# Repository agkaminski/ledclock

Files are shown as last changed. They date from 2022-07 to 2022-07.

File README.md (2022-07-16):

# LEDclock
Big DIY clock based on LED filaments.
# Introduction
LEDclock project is a simple, yet very big and bright clock based on chinesium 3V LED filaments (designed to look like a incadescent bulb tungsten filament... from the distance, I guess).<br><br>
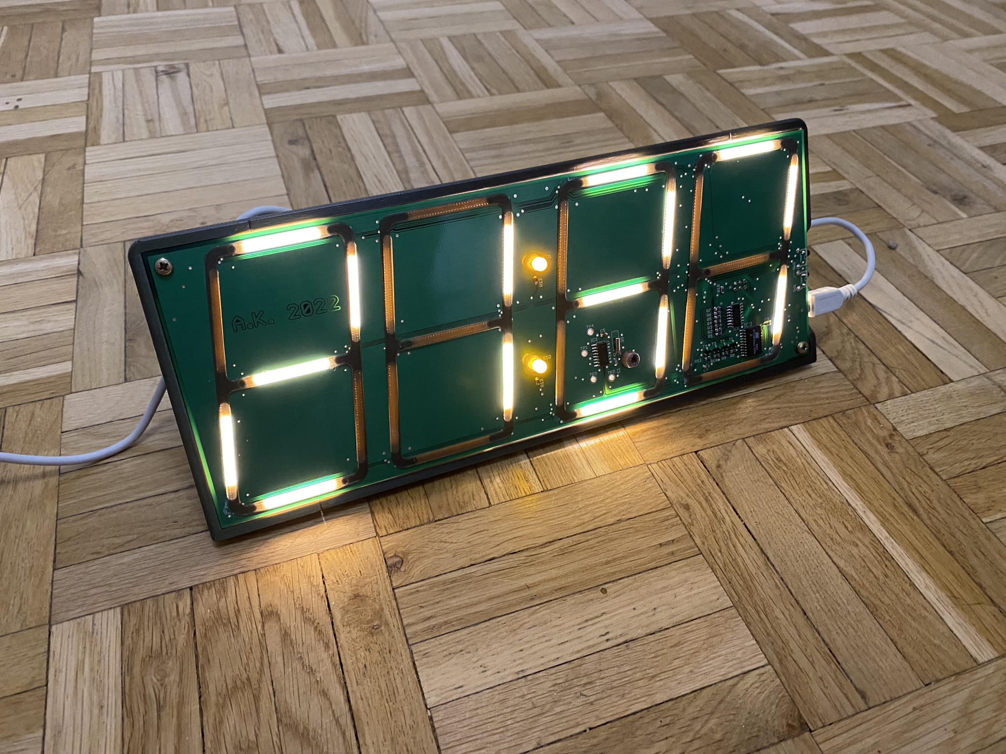
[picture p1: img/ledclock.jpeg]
LEDclock

# Features
- 24 hour clock,
- time setting via two buttons (one for minutes, one for hours),
- long press button to set time faster,
- blinking after power loss to indicate that the time is incorrect,
- RTC calibration with 1 ppm precision (+- 999 ppms),
- slow, gradual enabling/disabling changed screen segments (PWM),
- brightness setting,
- watchdog,
- calibration and brighness storage on the EEPROM.
# How to
To increment minutes press upper button, to increment hours press lower button. Long press for fast change
Press both buttons long to change mode. Available modes:
- RTC calibration,
- brightness setting,
- normal operation (clock mode).
After 5 seconds of buttons not being pressed display will return to clock mode.
## RTC calibration
Display: Cxxx for positive (making clock faster), Exxx for negative calibration. Press upper button to increase calibration value, lower button to decrease. Allows calibration from -999 to 999 ppm.
## Brighness
Display: b  x. Press upper button to increase brightness, lower to decrease. Brightness levels from 0 to 8 are available.
# I want to build one!
That's great! I am providing everything you need to make one yourself.
## Making PCB
Send gerber files to the PCB manufactuer of your choice. Make sure to get 28 milled slots done - it is essential, as LEDs are mounted on the bottom side and are viewed from the top side.
## Collecting elements
Please see the bom.csv file with all needed components. You can get LED filaments from here https://pl.aliexpress.com/item/4000478265055.html. Make sure to get 3V version!
## Soldering
This project uses pretty much only SMD elements, but all of them can be mounted using basic soldering iron.
**Dot LEDs can interfere with the ISP interface (depending on the programmer)!** Mount R12 and R13 resistors *after* downloading FW to the board.<br>
Watch out for LED filaments polarisation. + side is marked by a small hole in the lead - solder this side to the "common" side (the side that is connected to the neighbour LEDs).
## Sofware needed
To build FW you need *avr-gcc* along with *avr-libc*. To download the FW to the MCU you need *avrdude*.
## Downloading FW
My suggestion is to use USBasp programmer and avrdude software tool. I've provided needed commands in Makefile.
First we need to set fuse byte to change default 1 MHz CPU clock to 8 MHz:<br>
*make fuse*<br>
then we can download FW:<br>
*make install*<br>
Done! The clock should now be ready to be used.
## Housing 3D print
Housing is too big for most 3D printers to fit, so it was designed to be able to split into 3 parts. You need to split 30 mm on both sides. Three pieces can then be reattached by using 4 M4x25 (conical head) and 2 M3x50 screws. Many other screw lengths will do the trick. PCB is attached to the housing using 2 M3x8 screws.<br><br>
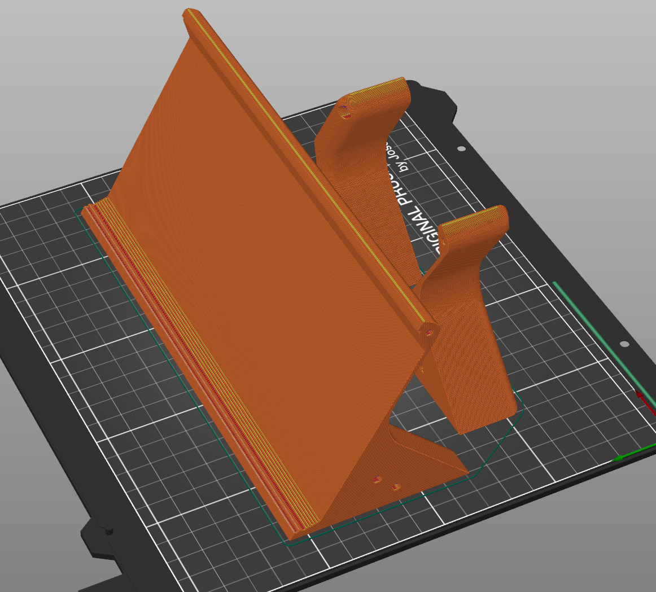
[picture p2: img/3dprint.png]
Housing split on the build plate

## Filter
LED filaments give huge brightness but poor constrast - filter is needed. Print 4 times *filter.stl*, use dark filament for best result, 0.2 mm layer height. Put them into slots on the top side and hold them in place with a little drops of superglue.<br>
Screen without the filters:<br>
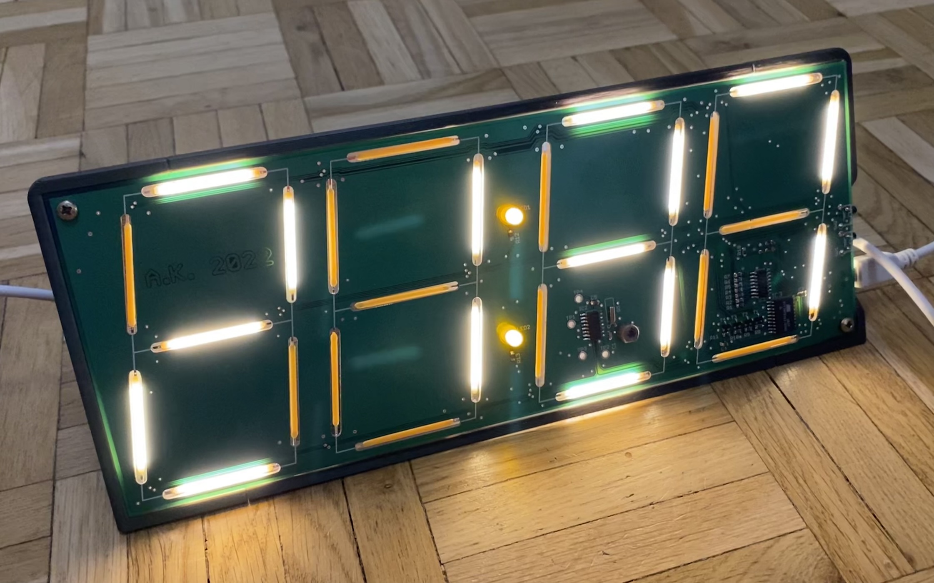
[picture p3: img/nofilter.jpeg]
Nofilter No filter

# License
Free for non-commercial use and educational purposes. See LICENSE.md for details.
# Donations
If you like my project and would like to endorse me, you can donate any BTC amount to the address:<br><br>
3EL4b7g72awqXzzVFQan2h2PmizMhSSYMX<br><br>
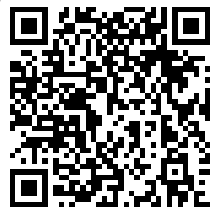
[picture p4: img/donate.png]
Donation

# Photos
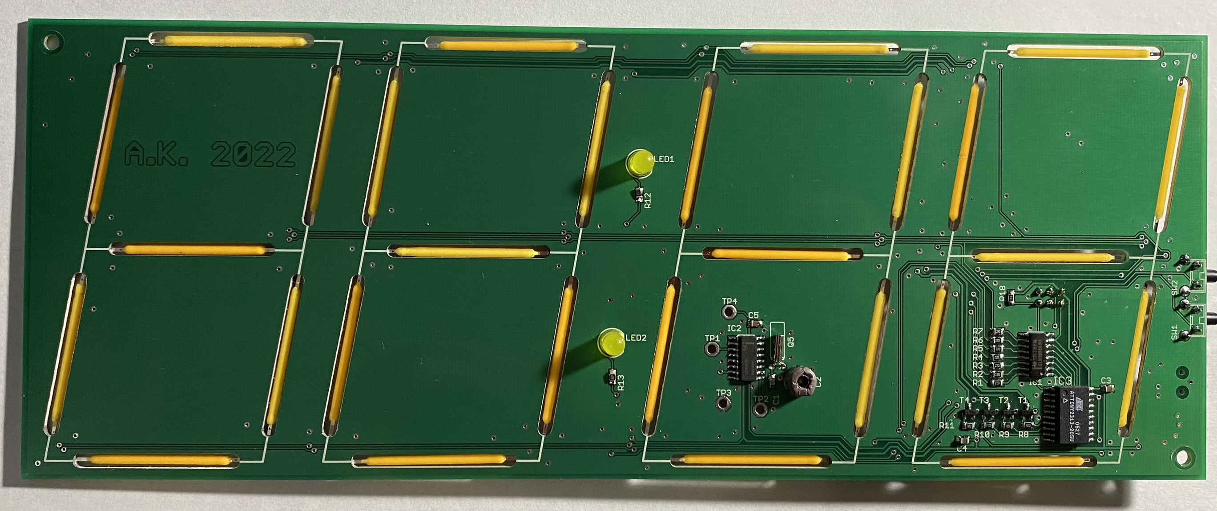
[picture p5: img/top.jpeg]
Top
<br><br>
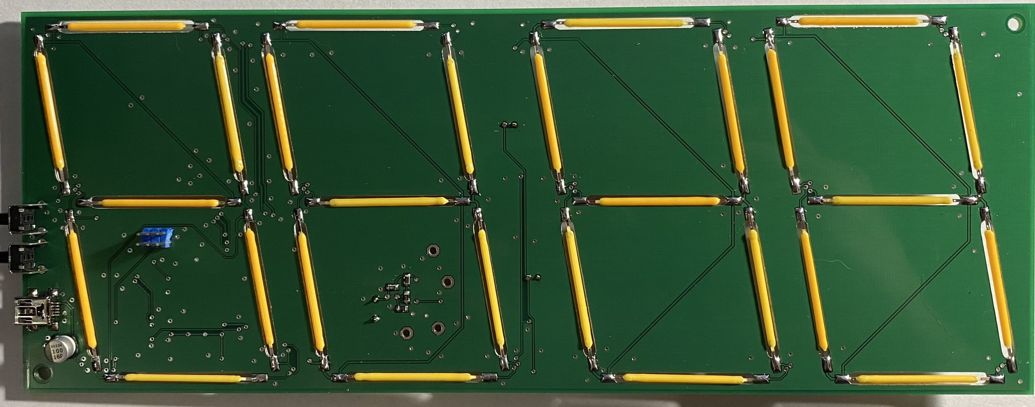
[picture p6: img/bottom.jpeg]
Bottom


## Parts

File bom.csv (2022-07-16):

Qty | Value | Device | Package | Parts | Description
1 | 100u | CPOL-EUC | PANASONIC_C | C6 | POLARIZED CAPACITOR, European symbol
1 | 32K | CRYSTALTC38H | TC38H | Q5 | CRYSTAL
2 | yellow | LED5MM | LED5MM | LED1, LED2 | LED
1 |  | USBMINIB | USB-MINIB | CN1 | USB Connectors
1 | 10-50p | C-TRIMMTZ03 | CTRIMTZ03 | C2 | Trimm capacitor
3 | 100n | C-EUC0805 | C0805 | C3, C5 | CAPACITOR, European symbol
1 | 10K | R-EU_R0805 | R0805 | R18 | RESISTOR, European symbol
1 | 10p | C-EUC0805 | C0805 | C1 | CAPACITOR, European symbol
4 | 1K | R-EU_R0805 | R0805 | R8, R9, R10, R11 | RESISTOR, European symbol
7 | 22R | R-EU_R0805 | R0805 | R1, R2, R3, R4, R5, R6, R7 | RESISTOR, European symbol
1 | 22u | C-EUC0805 | C0805 | C4 | CAPACITOR, European symbol
1 | 330K | R-EU_R0805 | R0805 | R17 | RESISTOR, European symbol
2 | 330R | R-EU_R0805 | R0805 | R12, R13 | RESISTOR, European symbol
1 | 4060D | 4060D | SO16 | IC2 | 14-stage binary/ripple COUNTER
3 | 5M1 | R-EU_R0805 | R0805 | R14, R15, R16 | RESISTOR, European symbol
1 | AVRISP-6 | AVRISP-6 | AVRISP | ISP1 | AVR ISP HEADER
4 | BC807-40 | BC807-40-PNP-SOT23-BEC | SOT23-BEC | T1, T2, T3, T4 | PNP Transistror
28 | LED_39MM | LED_39MM | LED_39MM | L1A, L1B, L1C, L1D, L1E, L1F, L1G, L2A, L2B, L2C, L2D, L2E, L2F, L2G, L3A, L3B, L3C, L3D, L3E, L3F, L3G, L4A, L4B, L4C, L4D, L4E, L4F, L4G | 3V version https://pl.aliexpress.com/item/4000478265055.html
2 | SW_TACT_4P_B | SW_TACT_4P_B | SW_TACT_STANDARD_RIGHT_ANGLE | SW1, SW2 | Mount on BOTTOM side
1 | TINY2313-*S* | TINY2313-*S* | SO20 | IC3 | Atmel Tiny2313
4 | TPPAD1-20 | TPPAD1-20 | P1-20 | TP1, TP2, TP3, TP4 | Test pad
1 | ULN2003AD | ULN2003AD | SO16 | IC1 | DRIVER ARRAY

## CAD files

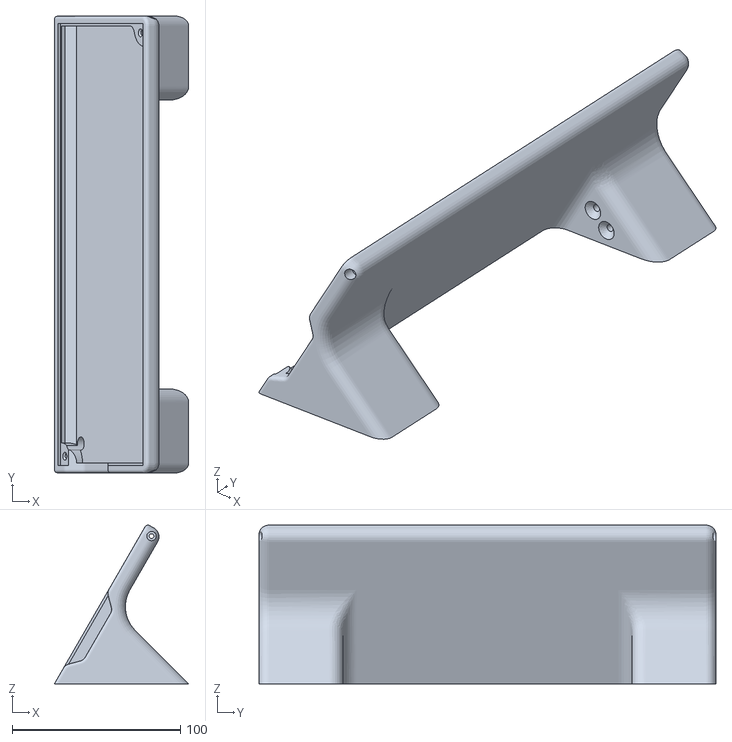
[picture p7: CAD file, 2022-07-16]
housing.stl
80.0 x 272.0 x 94.5

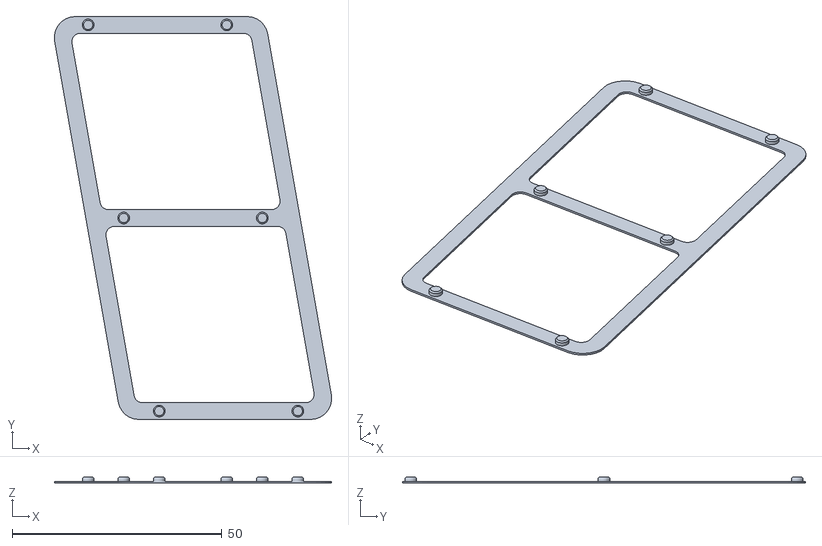
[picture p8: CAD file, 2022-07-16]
filter.stl
66.0 x 96.0 x 1.40

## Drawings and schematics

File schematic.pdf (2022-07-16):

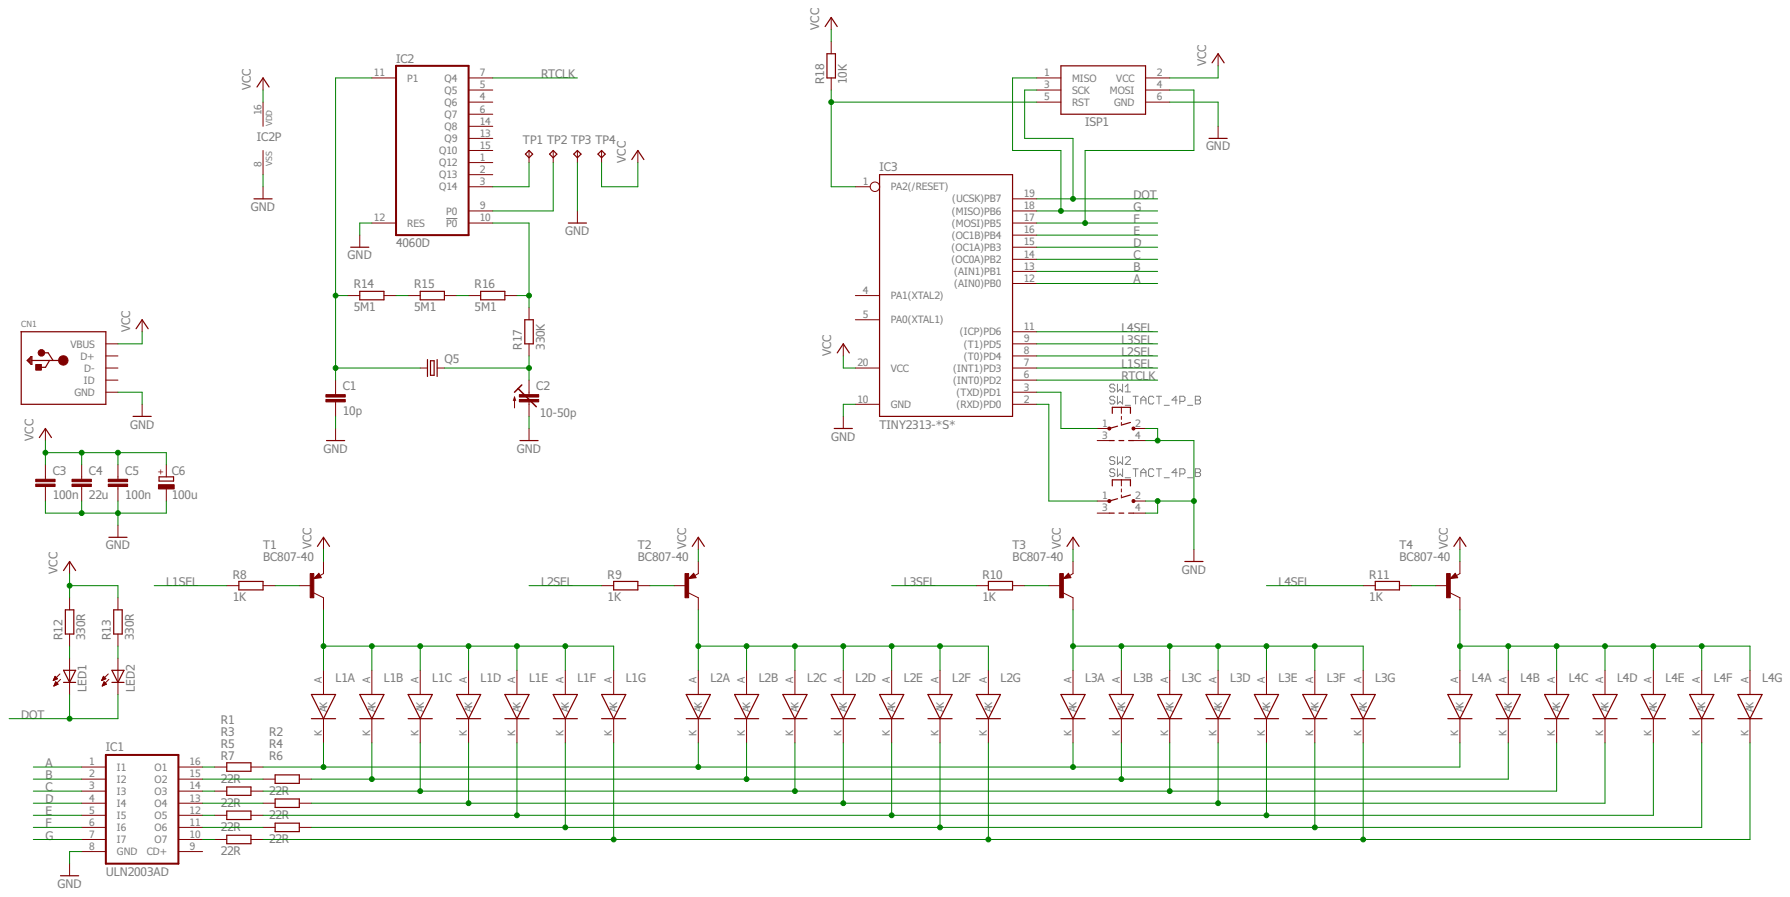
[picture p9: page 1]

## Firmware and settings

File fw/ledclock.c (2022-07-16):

/* LEDclock Firmware
 * Developed for Atmel ATTiny2313 MCU
 * HW rev A
 *
 * LEDclock project is a simple, yet very big and bright clock
 * based on chinesium 3V LED filaments (designed to look like a
 * incadescent bulb tungsten filament... from the distance, I guess)
 *
 * Features of this FW:
 * - 24 hour clock,
 * - time setting via two buttons (one for minutes, one for hours),
 * - long press button to set time faster,
 * - blinking after power loss to indicate that the time is incorrect,
 * - RTC calibration with 1 ppm precision (+- 999 ppms),
 * - slow, gradual enabling/disabling changed screen segments (PWM),
 * - brightness setting (0-7),
 * - watchdog,
 * - calibration and brighness storage on eeprom.
 *
 * Copyright 2022 Aleksander Kaminski
 *
 * Free for non-commercial use and education purposes.
 */

#include <avr/interrupt.h>
#include <avr/io.h>
#include <avr/sleep.h>
#include <avr/wdt.h>
#include <avr/eeprom.h>

#define BUTTON_COOLDOWN  200  /* In about 1 ms */
#define BUTTON_LONGPRESS 2000 /* In about 1 ms */
#define LONGPRESS_HZ     4    /* How fast is autopress working */
#define BRIGHTNESS       50   /* Base brightness (x/256) */
#define BRIGHTNESS_STEP  25
#define LED_VOID         10   /* Code for empty digit */
#define RTC_CALIB        0    /* +-ppm */
#define RTC_HZ           2048
#define RAMP_MIN         10   /* Minimal PWM (x/256) */
#define RAMP_MAX         (BRIGHTNESS + (g_brightness * BRIGHTNESS_STEP) - 10)
#define RAMP_INC         2    /* Increased on every screen refresh (122 Hz) */
#define ADDR_CALIBRATION ((void *)0)
#define ADDR_BRIGHNESS   ((void *)2)


typedef unsigned char byte;


int g_subseconds;
unsigned int g_seconds_calib_cnt;
byte g_seconds;
byte g_minutes;
byte g_hours = 12;
byte g_time_set;

byte g_led_on[4];
byte g_led_rampup[4];
byte g_led_rampdown[4];
byte g_rampcnt = RAMP_MIN;
byte g_curr_digit;

unsigned int g_button_presscnt[2];
enum {
	button_not_active,
	button_active,
	button_longpress,
	button_lockup
} g_button_state[2] = { button_not_active, button_not_active };

enum {
	mode_normal = 0,
	mode_calib,
	mode_brightness,
	mode_end
} g_mode = mode_normal;
byte g_mode_timeout;
int g_rtc_calib = RTC_CALIB;
byte g_brightness = 4;


static void set_brightness(void)
{
	OCR0B = BRIGHTNESS + (g_brightness * BRIGHTNESS_STEP);
}


static void store_params(void)
{
	eeprom_write_word(ADDR_CALIBRATION, g_rtc_calib);
	eeprom_write_word(ADDR_BRIGHNESS, g_brightness);
}


static inline void restore_params(void)
{
	byte dataok = 1;

	g_rtc_calib = eeprom_read_word(ADDR_CALIBRATION);
	g_brightness = eeprom_read_word(ADDR_BRIGHNESS);

	if (g_rtc_calib > 999 || g_rtc_calib < -999) {
		g_rtc_calib = RTC_CALIB;
		dataok = 0;
	}

	if (g_brightness > 8) {
		g_brightness = 4;
		dataok = 0;
	}

	if (!dataok)
		store_params();

	set_brightness();
}



static inline void brightness_inc(void)
{
	if (g_brightness < 8)
		++g_brightness;

	set_brightness();
}


static inline void brightness_dec(void)
{
	if (g_brightness > 0)
		--g_brightness;

	set_brightness();
}


static inline void calib_inc(void)
{
	if (g_rtc_calib < 999)
		++g_rtc_calib;
}


static inline void calib_dec(void)
{
	if (g_rtc_calib > -999)
		--g_rtc_calib;
}


static void hours_inc(void)
{
	if (++g_hours >= 24)
		g_hours = 0;

	g_seconds = 0;
}


static void minutes_inc(void)
{
	if (++g_minutes >= 60) {
		g_minutes = 0;
		hours_inc();
	}

	g_seconds = 0;
}


static byte button_check(byte which)
{
	return !(PIND & (1 << which));
}


static byte button_handle(byte which)
{
	byte trigger = 0;

	if (button_check(which)) {
		if (g_button_presscnt[which] < BUTTON_LONGPRESS) {
			++g_button_presscnt[which];

			/* Debouncing */
			if (g_button_state[which] == button_not_active &&
					g_button_presscnt[which] >= BUTTON_COOLDOWN) {
				g_button_state[which] = button_active;
				trigger = 1;
			}
		}
		else if (g_button_state[which] != button_lockup) {
			g_button_state[which] = button_longpress;
		}
	}
	else {
		g_button_state[which] = button_not_active;
		g_button_presscnt[which] = 0;
	}

	return trigger;
}


static byte decode7seg(byte dig)
{
	static const byte lut[] = {
		0x3f, /* 0 */
		0x06, /* 1 */
		0x5b, /* 2 */
		0x4f, /* 3 */
		0x66, /* 4 */
		0x6d, /* 5 */
		0x7d, /* 6 */
		0x07, /* 7 */
		0x7f, /* 8 */
		0x6f, /* 9 */
		0x00, /* LED_VOID */
		0x7c, /* b */
		0x39, /* c */
		0x5e, /* d */
		0x79  /* e */
	};

	return lut[dig];
}


/* This function handles updating each screen digit.
 * Segments that are being enabled are not enabled
 * instantly, instead are put in separate ramp-up
 * register and being slowly lit on using PWM.
 * Same applies to segments that are being disabled,
 * but these are handled by ramp-down register.
 * As PWM for ramp-up increased, at the same time
 * PWM for ramp-down decreases. */
static void update_digit(byte which, byte newval)
{
	g_led_on[which] |= g_led_rampup[which];
	g_led_on[which] &= ~g_led_rampdown[which];

	byte diff = g_led_on[which] ^ newval;

	g_led_rampup[which] = diff & ~g_led_on[which];
	g_led_rampdown[which] = diff & g_led_on[which];
}


static void set_ramp(byte val)
{
	if (val < RAMP_MIN)
		val = RAMP_MIN;
	else if (val > RAMP_MAX)
		val = RAMP_MAX;

	OCR0A = val;
	g_rampcnt = val;
}


static void refresh_screen(int blanking)
{
	byte digit[4] = { LED_VOID, LED_VOID, LED_VOID, LED_VOID };

	switch (g_mode) {
		case mode_calib: {
			int calib_tmp = g_rtc_calib;
			if (calib_tmp < 0) {
				digit[0] = 0xe;
				calib_tmp = -calib_tmp;
			}
			else {
				digit[0] = 0xc;
			}

			for (signed char i = 3; i > 0; --i) {
				digit[i] = calib_tmp % 10;
				calib_tmp /= 10;
			}
			break;
		}

		case mode_brightness:
			digit[0] = 0xb;
			digit[3] = g_brightness;
			break;

		default:
			if (!blanking) {
				digit[0] = g_hours / 10;
				digit[1] = g_hours % 10;
				digit[2] = g_minutes / 10;
				digit[3] = g_minutes % 10;
			}
			break;
	}

	for (byte i = 0; i < 4; ++i)
		update_digit(i, decode7seg(digit[i]));

	set_ramp(RAMP_MIN);
}


static void set_dots(int state)
{
	PORTB &= ~(!state << 7);
	PORTB |= !!state << 7;
}


static void button_action(byte which)
{
	/* switch()...case takes less flash space than funtion LUT */
	switch (g_mode) {
		case mode_calib:
			if (!which)
				calib_inc();
			else
				calib_dec();
			break;

		case mode_brightness:
			if (!which)
				brightness_inc();
			else
				brightness_dec();
			break;

		default:
			if (!which)
				minutes_inc();
			else
				hours_inc();
			g_seconds = 0;
			break;
	}

	g_mode_timeout = 0;
}


ISR(INT0_vect)
{
	byte update = 0, blanking = 0, btrigger = 0;

	wdt_reset();

	/* Every second */
	if (++g_subseconds >= RTC_HZ) {
		g_subseconds -= RTC_HZ;

		/* Increment clock */
		if (++g_seconds >= 60) {
			minutes_inc();
			update = 1;
		}

		if (!g_time_set)
			update = 1;

		/* Handle dots and screen blinking when time is not set */
		if (g_seconds & 1) {
			set_dots(0);
			if (!g_time_set)
				blanking = 1;
		}
		else {
			set_dots(1);
		}

		/* Handle digital RTC calibration */
		if (++g_seconds_calib_cnt >= RTC_HZ) {
			g_subseconds += g_rtc_calib * 2;
			g_seconds_calib_cnt = 0;
		}

		/* Handle special mode timeout */
		if (g_mode != mode_normal && ++g_mode_timeout > 5) {
			g_mode = mode_normal;
			update = 1;
			store_params();
		}
	}

	/* Handle buttons */
	if ((btrigger = button_handle(0)) != 0) {
		button_action(0);
	}
	else if ((btrigger = button_handle(1)) != 0) {
		button_action(1);
	}
	else if (g_button_state[0] == button_longpress &&
			g_button_state[1] == button_longpress) {
		if (++g_mode == mode_end) {
			g_mode = mode_normal;
			store_params();
		}

		g_button_state[0] = g_button_state[1] = button_lockup;
		update = 1;
	}
	else if (!(g_subseconds % (RTC_HZ / LONGPRESS_HZ))) {
		btrigger = 1;
		if (g_button_state[0] == button_longpress)
			button_action(0);
		else if (g_button_state[1] == button_longpress)
			button_action(1);
		else
			btrigger = 0;
	}

	if (btrigger) {
		update = 1;
		g_time_set = 1;
	}

	if (update)
		refresh_screen(blanking);
}


/* Select new digit */
ISR(TIMER0_OVF_vect)
{
	byte t = PORTB & ~(0x7f);
	byte dot = PORTB & 0x80;

	/* Enable on and ramp-up segments, ramp-down stay disabled */
	t |= ((g_led_on[g_curr_digit] |
		g_led_rampup[g_curr_digit]) &
		~g_led_rampdown[g_curr_digit]);
	PORTB = (t & ~0x80) | dot;

	PORTD &= ~(1 << (3 + g_curr_digit));
}


/* Stop ramp-up, start ramp-down */
ISR(TIMER0_COMPA_vect)
{
	if (g_rampcnt < RAMP_MAX) {
		byte dot = PORTB & 0x80;
		/* Disable ramp-up segments, enable ramp-down */
		byte t = PORTB & ~(g_led_rampup[g_curr_digit]);
		PORTB = dot | ((t | g_led_rampdown[g_curr_digit]) & 0x7f);
	}
}


/* Disable screen (brightness control) */
ISR(TIMER0_COMPB_vect)
{
	PORTB &= ~(0x7f);
	PORTD |= 0xf << 3;
	g_curr_digit = (g_curr_digit + 1) % 4;

	if (!g_curr_digit)
		set_ramp(g_rampcnt + RAMP_INC);
}


int main(void)
{
	wdt_enable(WDTO_250MS);
	wdt_reset();

	/* Init screen */
	PORTB = 0;
	DDRB = 0xff;
	PORTD |= 0xf << 3;
	DDRD |= 0xf << 3;
	refresh_screen(0);

	/* Buttons - inputs, pull-up enable */
	PORTD |= (1 << 1) | (1 << 0);

	/* Real time clock interrupt generated by an external IC
	 * every 1/1024th of a second */
	DDRD &= ~(1 << 2);
	PORTD &= ~(1 << 2);
	/* Generate interrupt INT0 on rising edge */
	MCUCR |= (1 << ISC01) | (1 << ISC00);
	GIMSK |= 1 << INT0;

	/* Timer0 - screen management */
	/* Update OCRx at MAX */
	TCCR0A = (1 << WGM01) | (1 << WGM00);
	set_ramp(RAMP_MIN);
	set_brightness();
	TIMSK |= (1 << OCIE0B) | (1 << TOIE0) | (1 << OCIE0A);
	/* Enable counter (1/64 prescaler) */
	TCCR0B = (1 << CS01) | (1 << CS00);

	/* Fetch brighness and calibration from eeprom */
	restore_params();

	/* Whole operation is performed in interrupts.
	 * Stay asleep if there's no interrupt active */
	sleep_enable();
	sei();

	while (1)
		sleep_cpu();

	return 0;
}

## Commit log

2022-07-16 Added PCB gerber files
    [b.gbl, bs.gbs, opis.gbl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]
2022-07-16 Code cleanup and added features: - setting brightness in runtime, - setting rtc calibration in runtime
2022-07-16 Added schematic print
2022-07-16 Updated schematic: added missing values
2022-07-16 fs: small optimalizations. Fixed dot being set by screen routines
    [ledclock.c]
2022-07-16 Added housing stl model
    [housing.stl]
2022-07-16 Fixes after first testing. Added params backup to eeprom
    [ledclock.c]
2022-07-16 Added BOM
    [bom.csv]
2022-07-16 Updated schematic and BOM (capacitor values)
    [bom.csv]
2022-07-16 Fixed screw lengths
2022-07-16 Added screen contrast increase filter
    [filter.stl]
2022-07-16 Fixed RTC calibration setting boundary. Use default for init
    [ledclock.c]
